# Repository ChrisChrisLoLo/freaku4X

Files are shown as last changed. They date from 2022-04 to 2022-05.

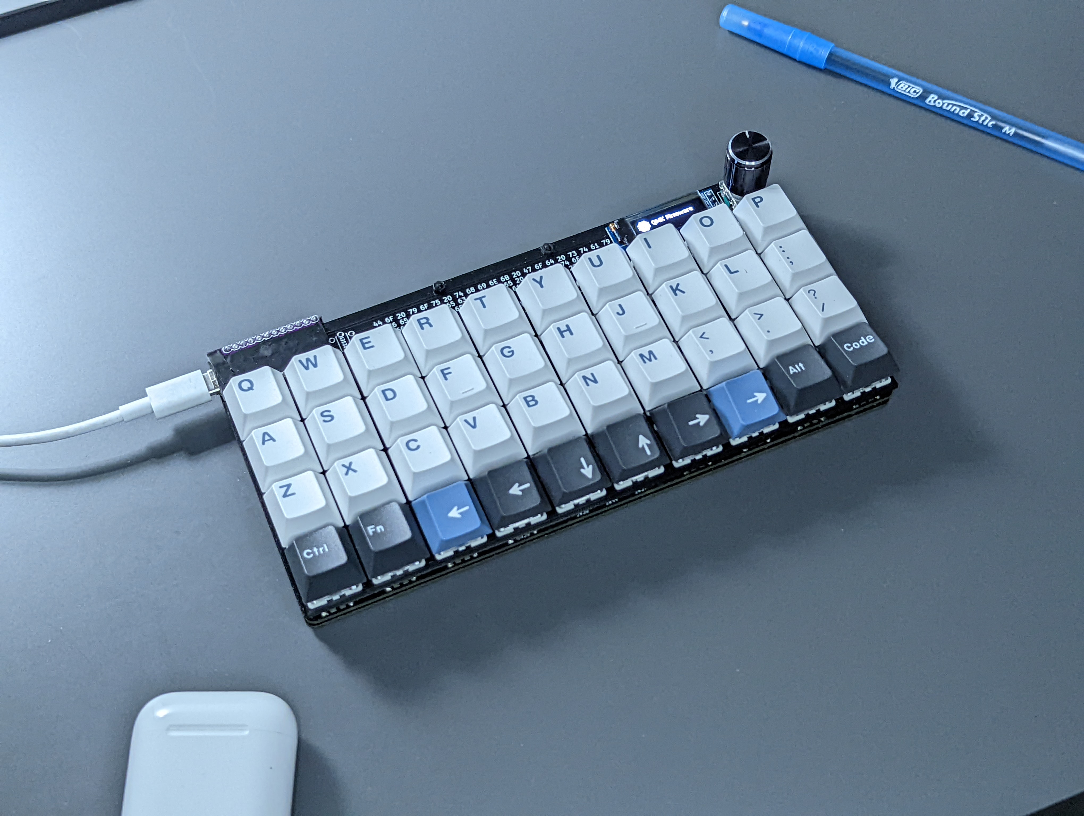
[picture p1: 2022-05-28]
docs/images/PXL_20220524_040610108 (1).jpg

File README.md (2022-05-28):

# freaku4X

A 4x10 ortho keyboard with a knob and OLED. It embraces the excess minimalism of the key count, and embraces the excess extravagence of a knob and oled screen. It also has a lower profile than your typical 4x10 orthos, since the microcontroller is facing upwards rather than downwards.

freaku4X

## Status
Prototyping phase. While possible to print and use right now, a few refinements can be made.
Right now, the knob button needs to be placed on the key matrix, and I would prefer to rotate the keys around so that hotswap is southfacing.

With that said, this keyboard in it's current form is usable with some amount of tinkering

## Acknowledgements
Thank you to [PCBWay](https://www.pcbway.com/) for allowing me to experiment and create wild board designs that I wouldn't be able to prototype without their support. PCBWay has always been super friendly with their service, and the quality of thier boards are great, so I do recommend using their services. The've also been supporting the custom pcb keyboard community for a while, allowing for the hobby to continue to flourish.

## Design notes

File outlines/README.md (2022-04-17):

# Outlines
Use https://kbplate.ai03.com/ to generate plate since http://builder.swillkb.com/ is dead and down currently

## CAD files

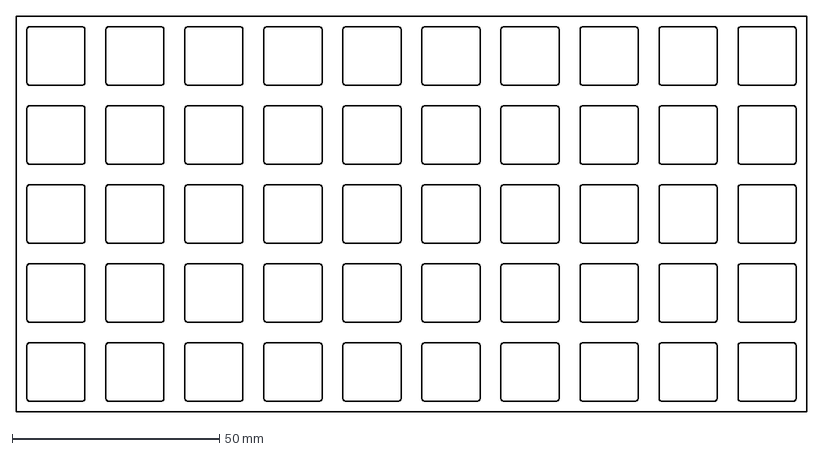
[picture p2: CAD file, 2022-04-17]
outlines/plate-2022-04-17T22_16_30.654Z.dxf
190.5 x 95.2 mm

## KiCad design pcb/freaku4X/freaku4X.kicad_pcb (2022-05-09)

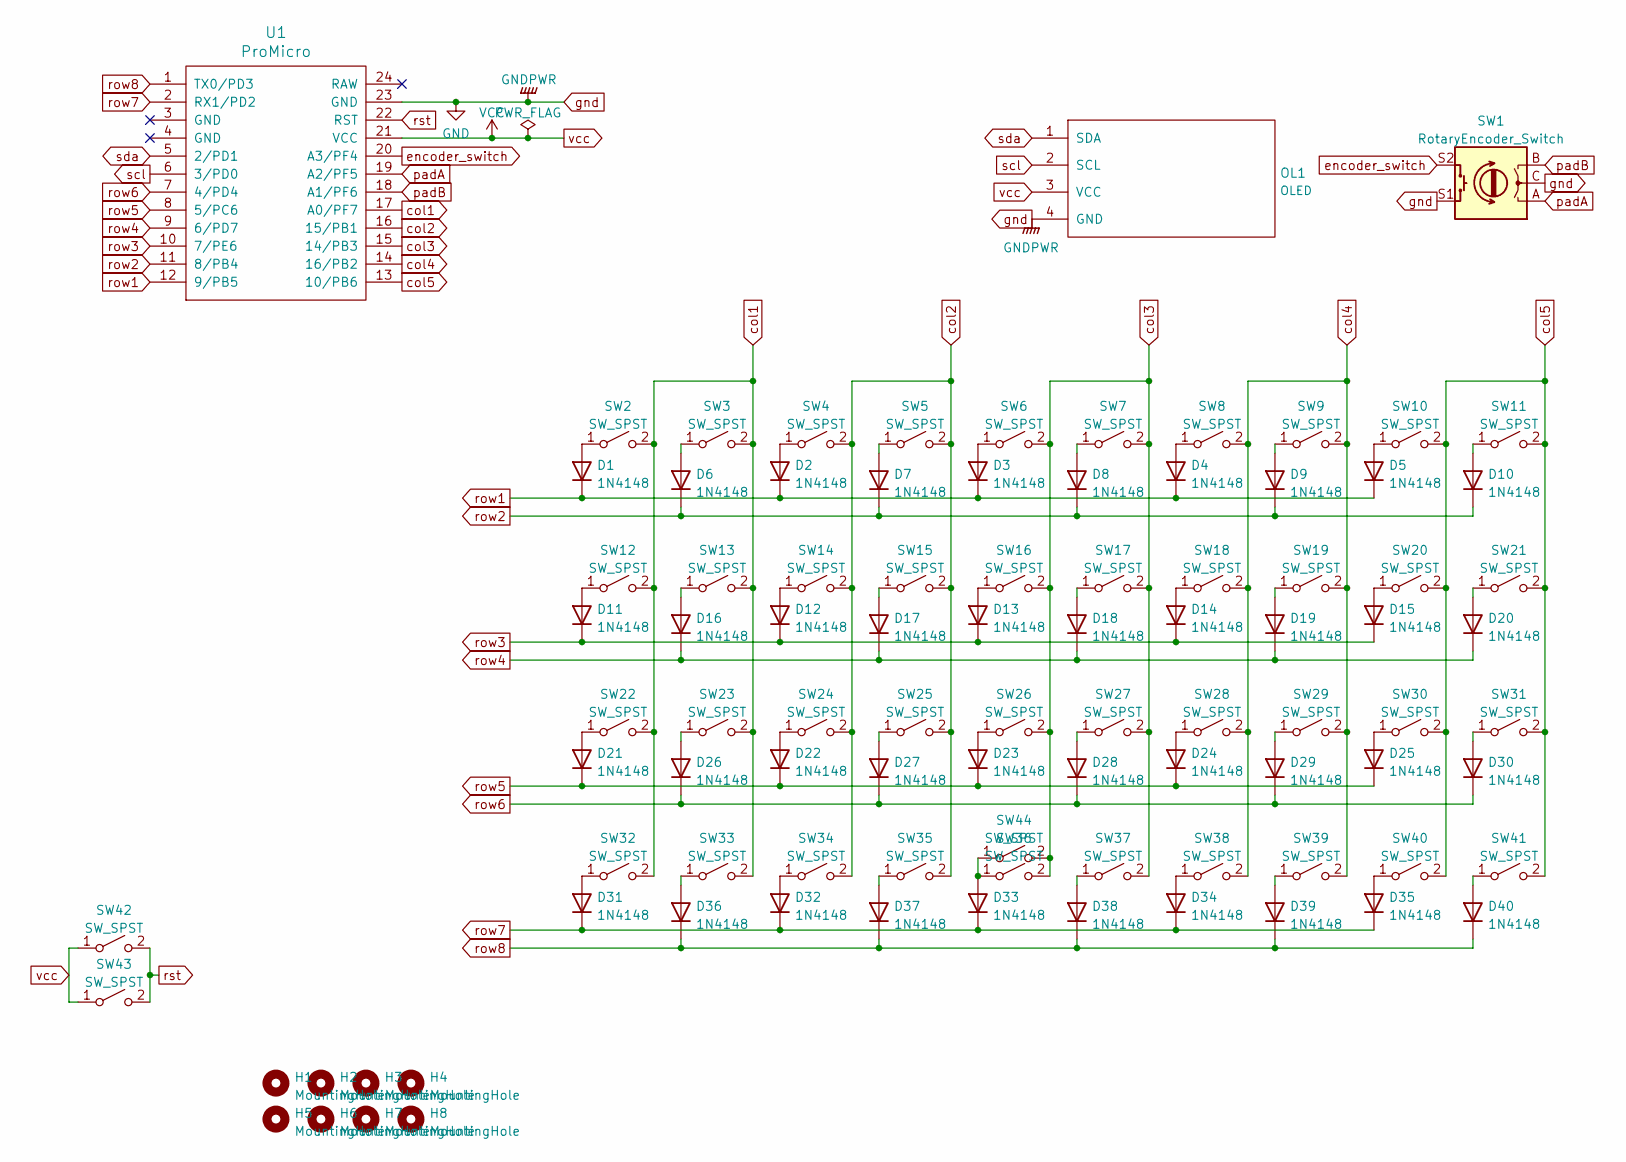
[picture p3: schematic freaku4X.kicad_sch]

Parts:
D1, D2, D3, D4, D5, D6, D7, D8, D9, D10, D11, D12, D13, D14, D15, D16, D17, D18, D19, D20, D21, D22, D23, D24, D25, D26, D27, D28, D29, D30, D31, D32, D33, D34, D35, D36, D37, D38, D39, D40: 1N4148
H1, H2, H3, H4, H5, H6, H7, H8: MountingHole; MountingHole_2.2mm_M2
OL1: OLED; OLED_v2
SW1: RotaryEncoder_Switch; RotaryEncoder_Alps_EC11E-Switch_Vertical_H20mm
SW2, SW3, SW4, SW5, SW6, SW7, SW8, SW9, SW10, SW11, SW12, SW13, SW14, SW15, SW16, SW17, SW18, SW19, SW20, SW21, SW22, SW23, SW24, SW25, SW26, SW27, SW28, SW29, SW30, SW31, SW32, SW33, SW34, SW35, SW36, SW37, SW38, SW39, SW40, SW41: SW_SPST; Kailh_socket_MX_optional
SW42: SW_SPST; ResetSW_4
SW43: SW_SPST; ResetSW
SW44: SW_SPST; SW_MX
U1: ProMicro; ProMicro_v3

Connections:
unnamed: D1.2 (A), SW2.1 (A)
unnamed: D2.2 (A), SW4.1 (A)
unnamed: D3.2 (A), SW6.1 (A)
unnamed: D4.2 (A), SW8.1 (A)
unnamed: D5.2 (A), SW10.1 (A)
unnamed: D6.2 (A), SW3.1 (A)
unnamed: D7.2 (A), SW5.1 (A)
unnamed: D8.2 (A), SW7.1 (A)
unnamed: D9.2 (A), SW9.1 (A)
unnamed: D10.2 (A), SW11.1 (A)
unnamed: D11.2 (A), SW12.1 (A)
unnamed: D12.2 (A), SW14.1 (A)
unnamed: D13.2 (A), SW16.1 (A)
unnamed: D14.2 (A), SW18.1 (A)
unnamed: D15.2 (A), SW20.1 (A)
unnamed: D16.2 (A), SW13.1 (A)
unnamed: D17.2 (A), SW15.1 (A)
unnamed: D18.2 (A), SW17.1 (A)
unnamed: D19.2 (A), SW19.1 (A)
unnamed: D20.2 (A), SW21.1 (A)
unnamed: D21.2 (A), SW22.1 (A)
unnamed: D22.2 (A), SW24.1 (A)
unnamed: D23.2 (A), SW26.1 (A)
unnamed: D24.2 (A), SW28.1 (A)
unnamed: D25.2 (A), SW30.1 (A)
unnamed: D26.2 (A), SW23.1 (A)
unnamed: D27.2 (A), SW25.1 (A)
unnamed: D28.2 (A), SW27.1 (A)
unnamed: D29.2 (A), SW29.1 (A)
unnamed: D30.2 (A), SW31.1 (A)
unnamed: D31.2 (A), SW32.1 (A)
unnamed: D32.2 (A), SW34.1 (A)
unnamed: D33.2 (A), SW36.1 (A), SW44.1 (A)
unnamed: D34.2 (A), SW38.1 (A)
unnamed: D35.2 (A), SW40.1 (A)
unnamed: D36.2 (A), SW33.1 (A)
unnamed: D37.2 (A), SW35.1 (A)
unnamed: D38.2 (A), SW37.1 (A)
unnamed: D39.2 (A), SW39.1 (A)
unnamed: D40.2 (A), SW41.1 (A)
col1: SW2.2 (B), SW3.2 (B), SW12.2 (B), SW13.2 (B), SW22.2 (B), SW23.2 (B), SW32.2 (B), SW33.2 (B), U1.17 (A0/PF7)
col2: SW4.2 (B), SW5.2 (B), SW14.2 (B), SW15.2 (B), SW24.2 (B), SW25.2 (B), SW34.2 (B), SW35.2 (B), U1.16 (15/PB1)
col3: SW6.2 (B), SW7.2 (B), SW16.2 (B), SW17.2 (B), SW26.2 (B), SW27.2 (B), SW36.2 (B), SW37.2 (B), SW44.2 (B), U1.15 (14/PB3)
col4: SW8.2 (B), SW9.2 (B), SW18.2 (B), SW19.2 (B), SW28.2 (B), SW29.2 (B), SW38.2 (B), SW39.2 (B), U1.14 (16/PB2)
col5: SW10.2 (B), SW11.2 (B), SW20.2 (B), SW21.2 (B), SW30.2 (B), SW31.2 (B), SW40.2 (B), SW41.2 (B), U1.13 (10/PB6)
encoder_switch: SW1.S2, U1.20 (A3/PF4)
gnd: OL1.4 (GND), SW1.C, SW1.S1, U1.23 (GND)
padA: SW1.A, U1.19 (A2/PF5)
padB: SW1.B, U1.18 (A1/PF6)
row1: D1.1 (K), D2.1 (K), D3.1 (K), D4.1 (K), D5.1 (K), U1.12 (9/PB5)
row2: D6.1 (K), D7.1 (K), D8.1 (K), D9.1 (K), D10.1 (K), U1.11 (8/PB4)
row3: D11.1 (K), D12.1 (K), D13.1 (K), D14.1 (K), D15.1 (K), U1.10 (7/PE6)
row4: D16.1 (K), D17.1 (K), D18.1 (K), D19.1 (K), D20.1 (K), U1.9 (6/PD7)
row5: D21.1 (K), D22.1 (K), D23.1 (K), D24.1 (K), D25.1 (K), U1.8 (5/PC6)
row6: D26.1 (K), D27.1 (K), D28.1 (K), D29.1 (K), D30.1 (K), U1.7 (4/PD4)
row7: D31.1 (K), D32.1 (K), D33.1 (K), D34.1 (K), D35.1 (K), U1.2 (RX1/PD2)
row8: D36.1 (K), D37.1 (K), D38.1 (K), D39.1 (K), D40.1 (K), U1.1 (TX0/PD3)
rst: SW42.2 (B), SW43.2 (B), U1.22 (RST)
scl: OL1.2 (SCL), U1.6 (3/PD0)
sda: OL1.1 (SDA), U1.5 (2/PD1)
vcc: OL1.3 (VCC), SW42.1 (A), SW43.1 (A), U1.21 (VCC)

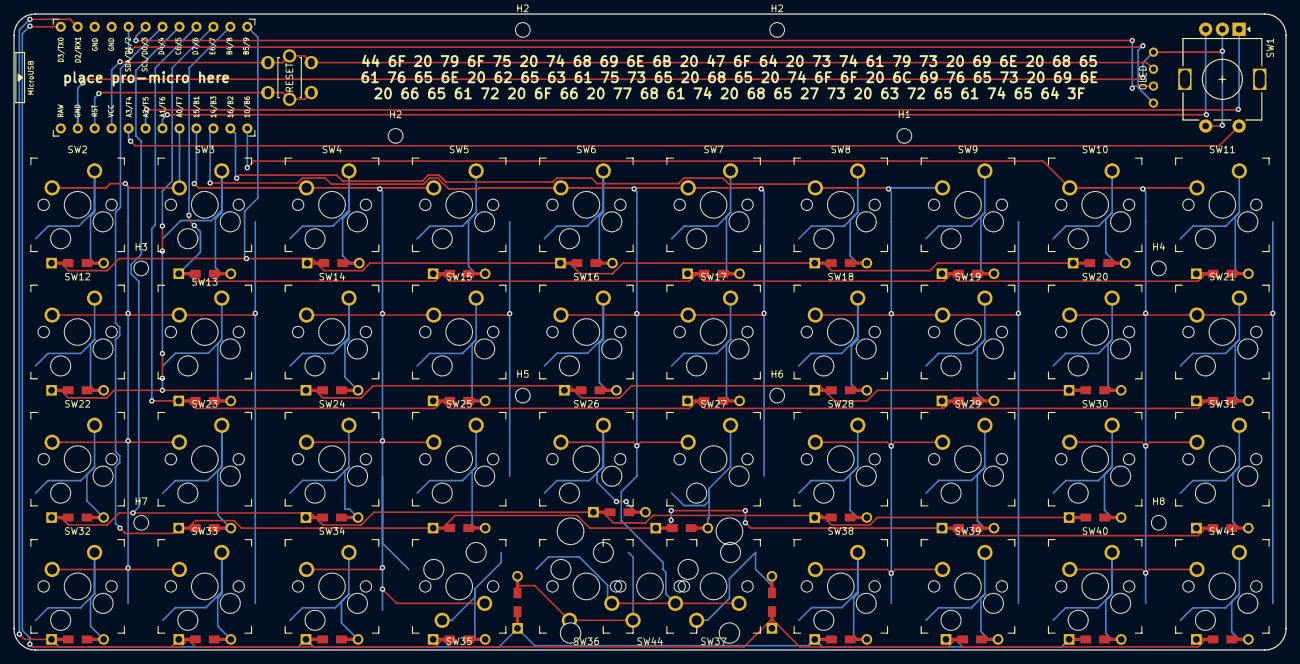
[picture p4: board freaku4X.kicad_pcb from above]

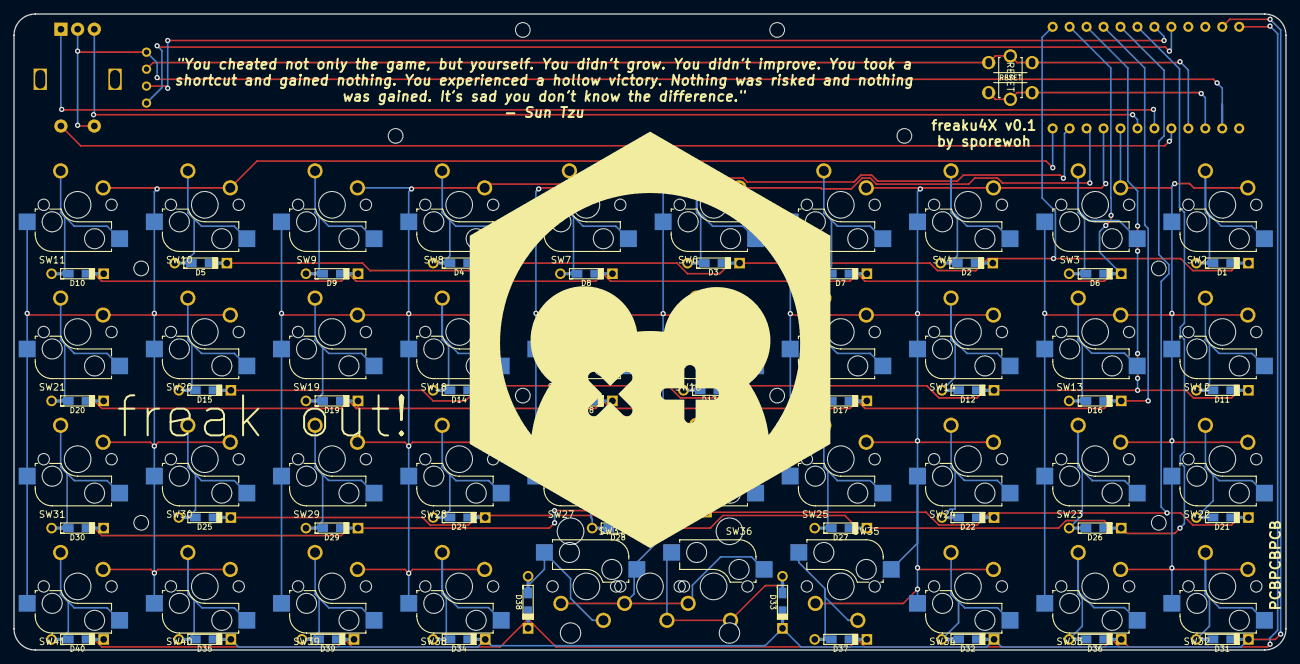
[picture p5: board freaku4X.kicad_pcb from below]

Board: 2 copper layers, 190.5 x 95.2 mm, 96 parts (41 on the bottom side), 61 nets.

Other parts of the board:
H2#2, H2#3: MountingHole; MountingHole_2.2mm_M2

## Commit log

2022-04-17 init project
    [freaku4X.kicad_pcb, freaku4X.sch, plate-2022-04-17T22_16_30.654Z.dxf]
2022-04-18 complete schematic
    [freaku4X.kicad_pcb, freaku4X.kicad_sch, freaku4X.sch]
2022-04-21 finish first iteration of PCB
    [freaku4X.kicad_pcb, freaku4X.kicad_sch]
2022-05-09 add gerbers
    [freaku4X-B_Cu.gbr, freaku4X-B_Mask.gbr, freaku4X-B_Paste.gbr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]
